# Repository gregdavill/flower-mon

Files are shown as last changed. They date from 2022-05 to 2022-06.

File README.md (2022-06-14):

# Zigbee Plant Watering Sensor

New circuit board layout based off the following projects:
 - https://github.com/smartboxchannel/Plant-Watering-Sensor-Zigbee
 - https://github.com/diyruz/flower

Capacitance sensor soil moisture sensor based on the CC2530 SoC.
Designed to communicate over Zigbee to a coordinator.
Powered from a CR2032, optional humidity, and temperature sensors.

## Photo
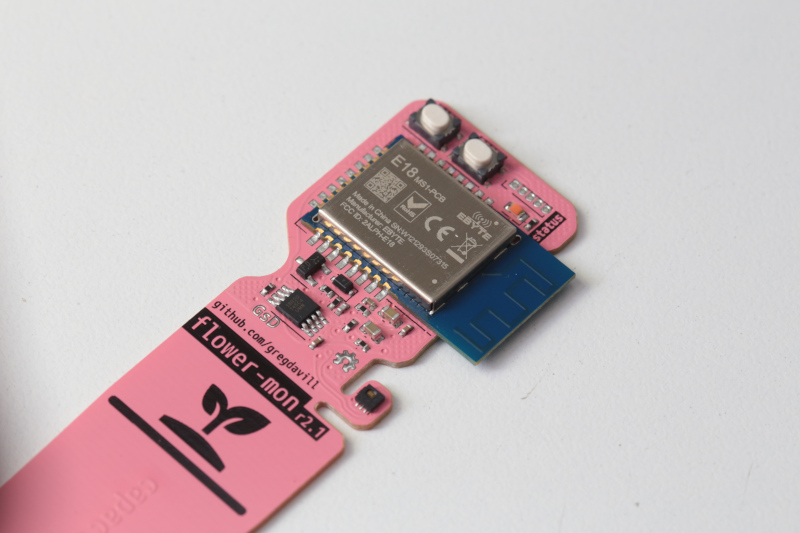
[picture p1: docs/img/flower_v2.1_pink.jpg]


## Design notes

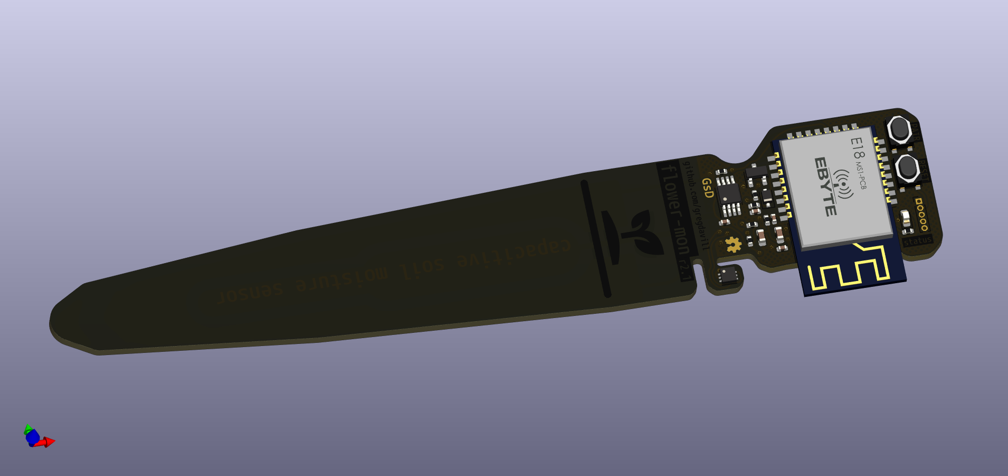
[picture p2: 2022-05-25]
docs/img/flower_v2.1_01.png

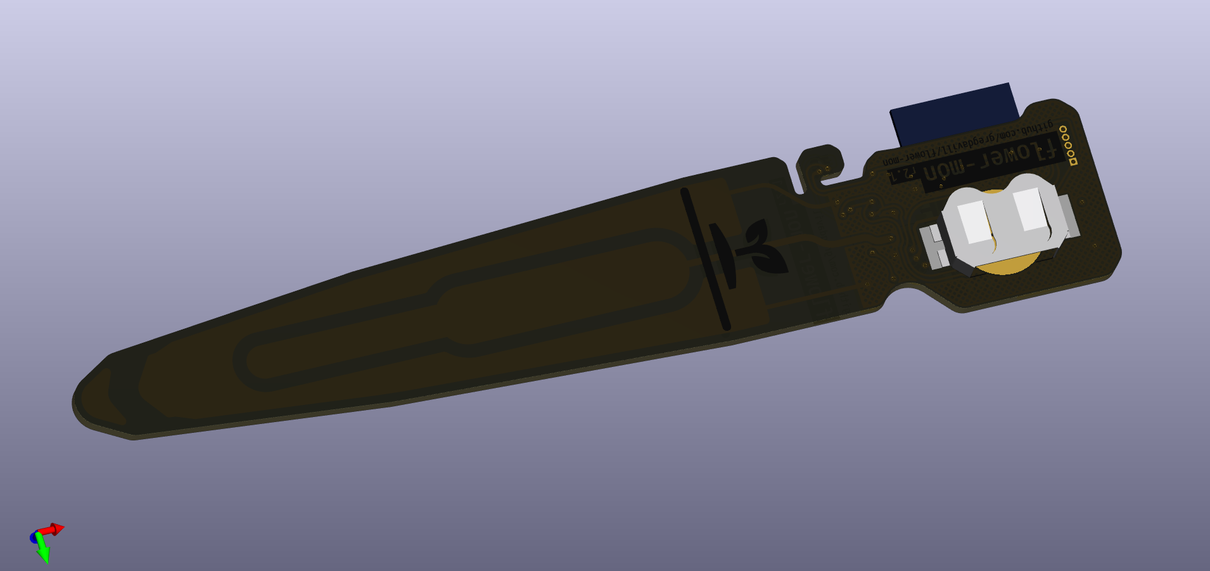
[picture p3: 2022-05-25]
docs/img/flower_v2.1_02.png

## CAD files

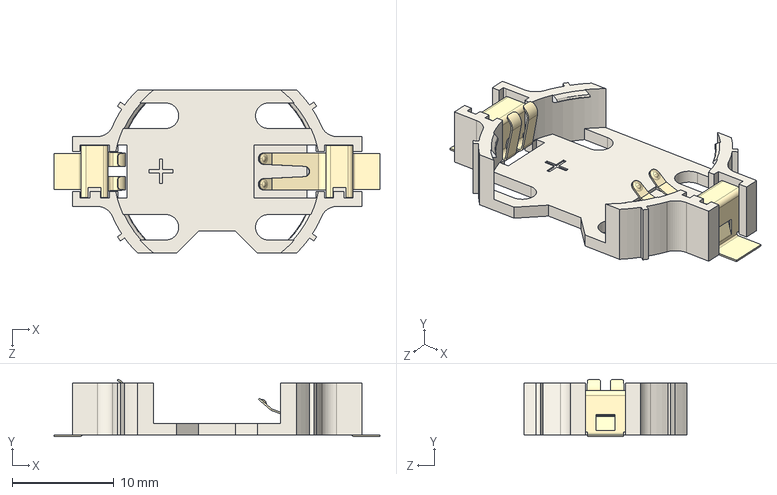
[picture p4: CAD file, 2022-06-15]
kicad-src/3d/keystone-PN1058.STEP
32.0 x 5.63 x 16.0 mm

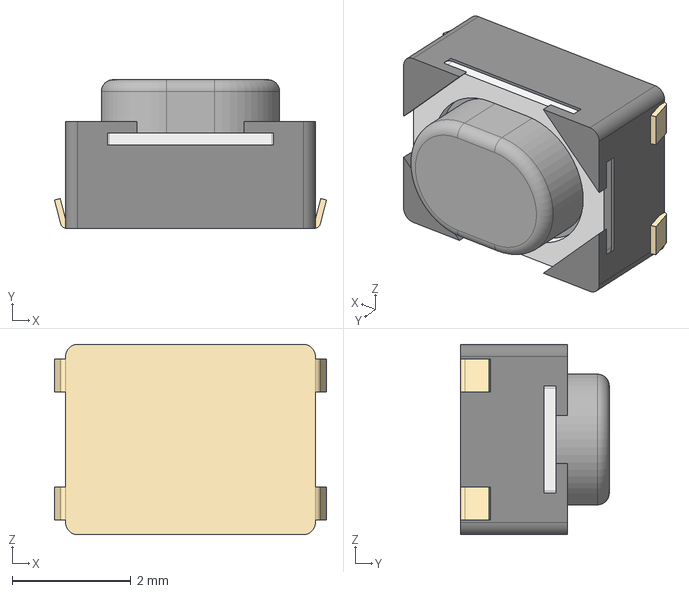
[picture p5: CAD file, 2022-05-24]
kicad-src/3d/PTS810SJG250SMTRLFS.step
4.58 x 2.50 x 3.20 mm

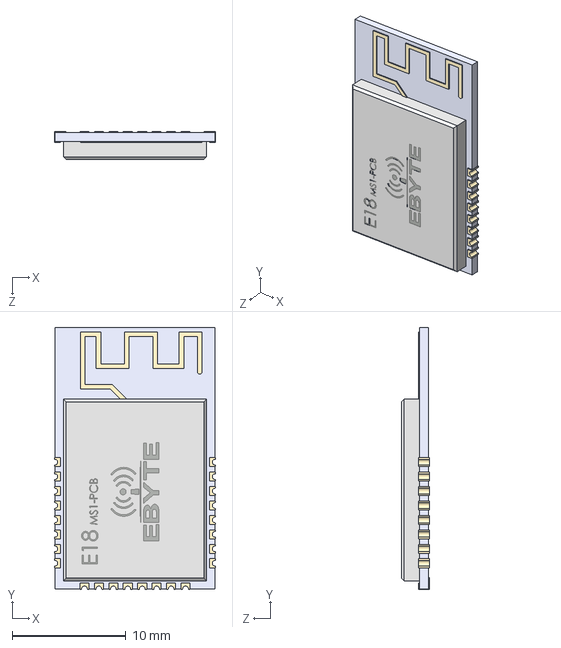
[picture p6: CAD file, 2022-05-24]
kicad-src/3d/e18-ms1-pcb.STEP
14.2 x 23.1 x 2.50 mm
plate
контакт x 24

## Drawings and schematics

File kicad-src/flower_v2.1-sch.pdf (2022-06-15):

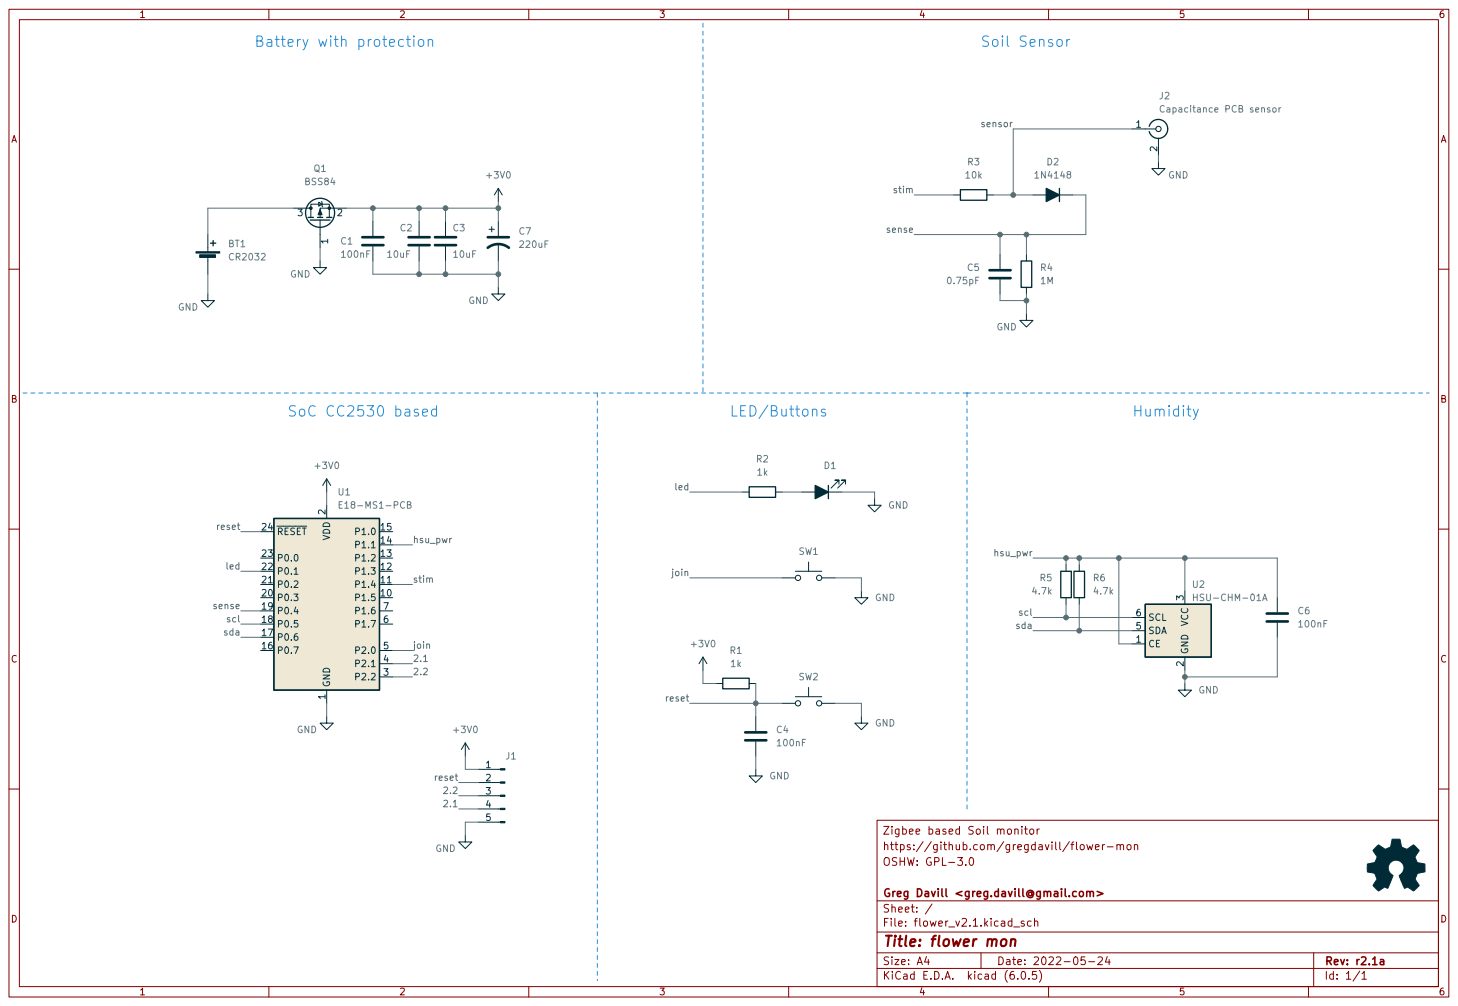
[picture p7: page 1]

3 SDA 5 SCL 6 U2HSU-CHM-01A GND

2 P0.3 20 P0.2 21 P0.1 22 P0.0 23 ~{RESET} 24 P2.2 3 P2.1 4 P2.0 5 P1.7 6 P1.6 7 U1E18-MS1-PCB GND GND

https://github.com/gregdavill/flower-mon
File: flower_v2.1.kicad_sch Sheet: / Greg Davill <greg.davill@gmail.com> OSHW: GPL-3.0

Id: 1/1 Title: flower mon

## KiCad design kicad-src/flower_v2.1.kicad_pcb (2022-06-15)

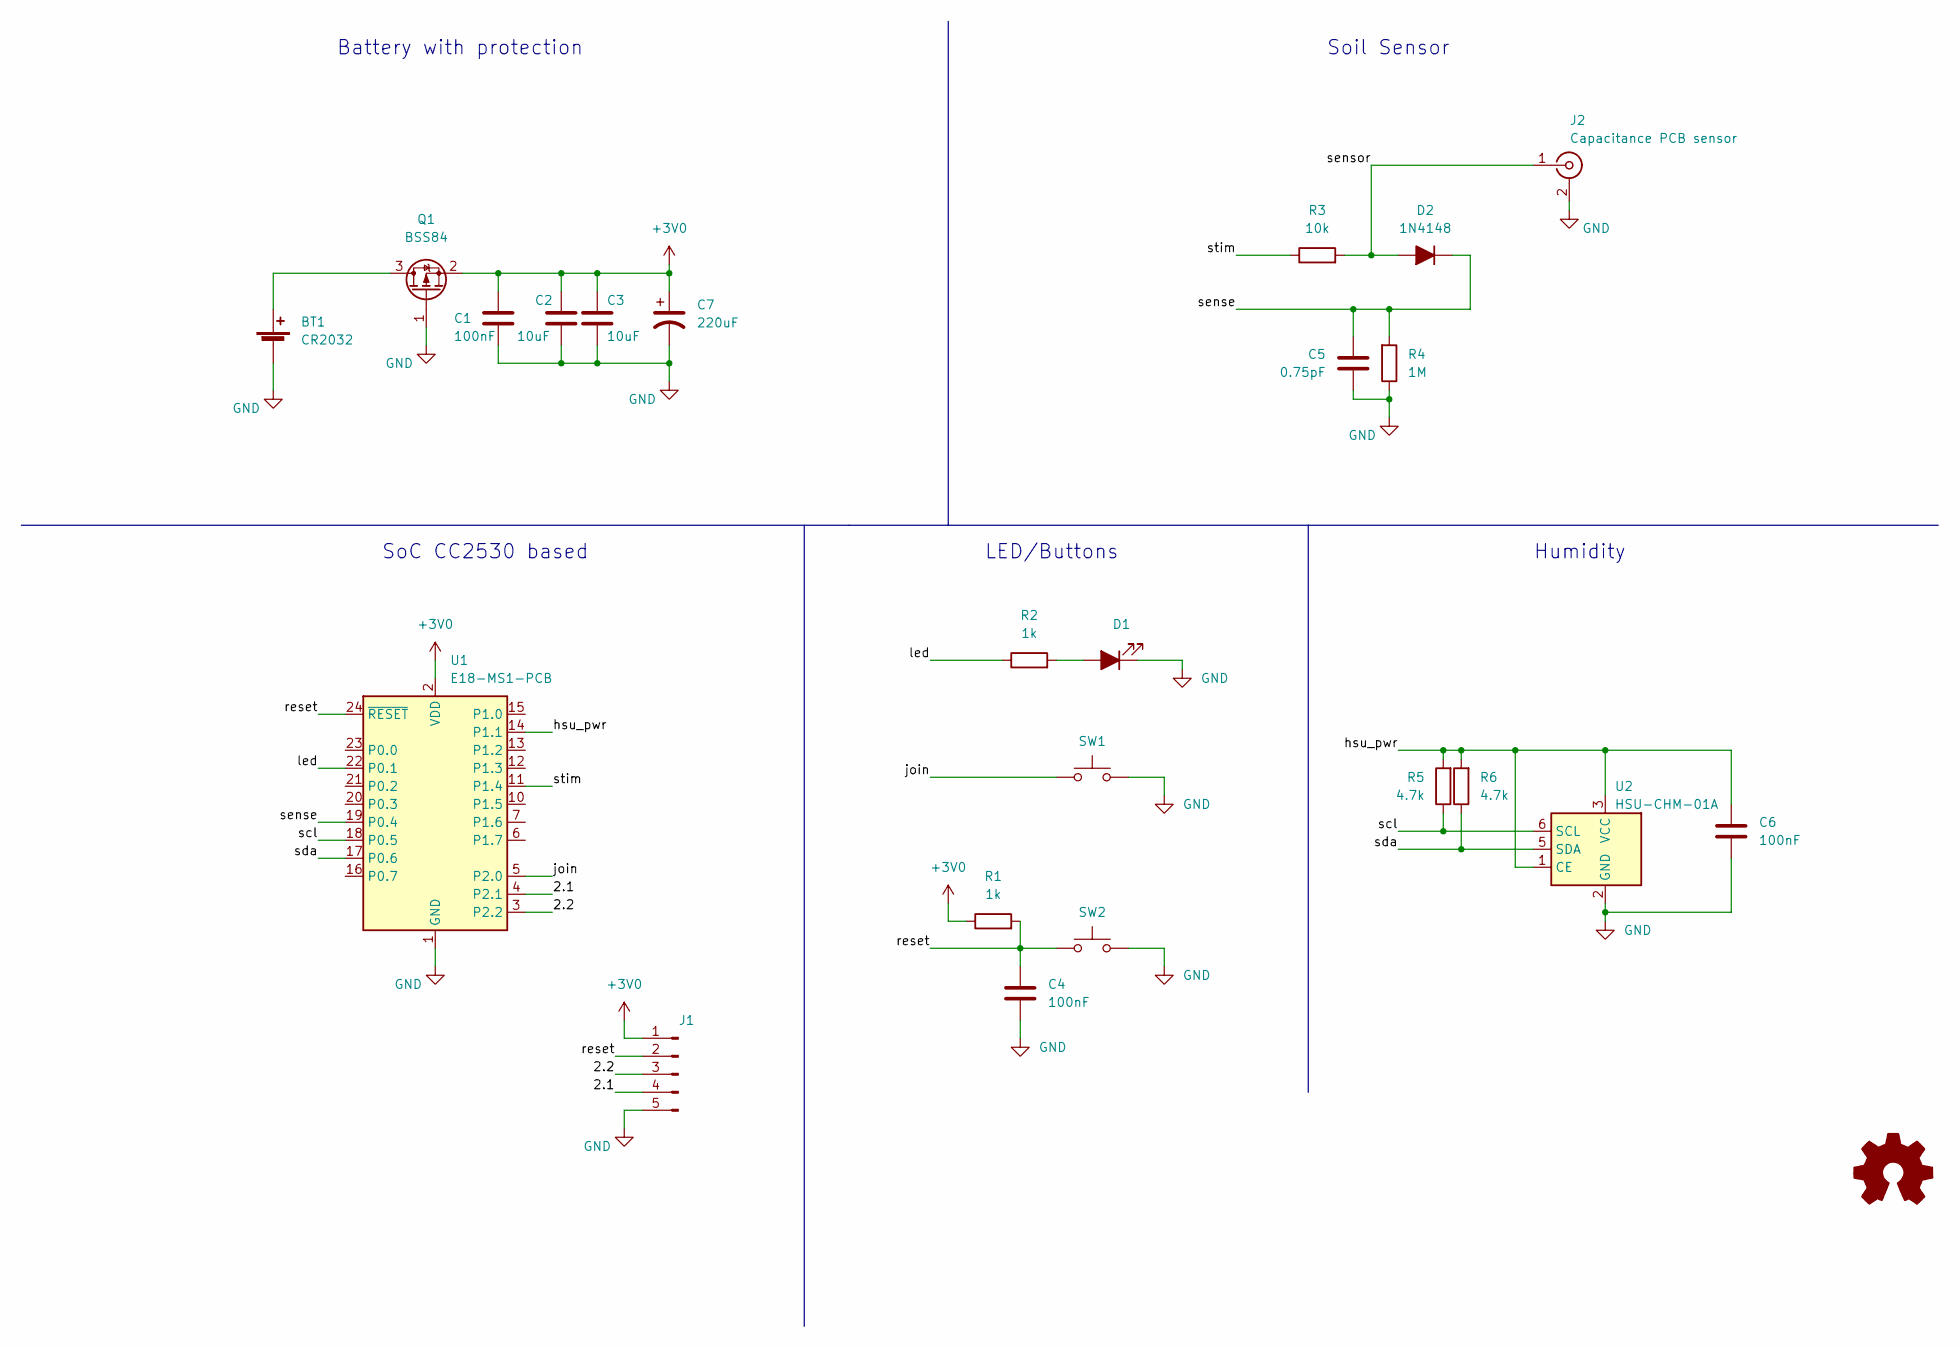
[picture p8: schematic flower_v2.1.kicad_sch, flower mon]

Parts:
BT1: CR2032; keystone_1058
C1, C4, C6: 100nF; C_0402_1005Metric
C2, C3: 10uF; C_0603_1608Metric
C5: 0.75pF; C_0402_1005Metric
C7: 220uF; CP_EIA-3528-21_Kemet-B
D1: green; LED_0603_1608Metric
D2: 1N4148; D_SOD-323F
J1: Conn_01x05_Male; PinHeader_1x05_P1.00mm_Vertical
J2: Capacitance PCB sensor
Q1: BSS84; SOT-23
R1, R2: 1k; R_0402_1005Metric
R3: 10k; R_0402_1005Metric
R4: 1M; R_0402_1005Metric
R5, R6: 4.7k; R_0402_1005Metric
SW1, SW2: SW_Push; SW_SPST_PTS810
U1: E18-MS1-PCB
U2: HSU-CHM-01A; DFN-6-1EP_2x2mm_P0.5mm_EP0.61x1.42mm

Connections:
+3V0: C1.1, C2.1, C3.1, C7.1, J1.1, Q1.2 (S), R1.1, U1.2 (VDD)
/2.1: J1.4, U1.4 (P2.1)
/2.2: J1.3, U1.3 (P2.2)
/hsu_pwr: C6.1, R5.2, R6.2, U1.14 (P1.1), U2.1 (CE), U2.3 (VCC)
/join: SW1.1, U1.5 (P2.0)
/led: R2.1, U1.22 (P0.1)
/reset: C4.1, J1.2, R1.2, SW2.1, U1.24 (~RESET)
/scl: R5.1, U1.18 (P0.5), U2.6 (SCL)
/sda: R6.1, U1.17 (P0.6), U2.5 (SDA)
/sense: C5.1, D2.1 (K), R4.2, U1.19 (P0.4)
/sensor: D2.2 (A), J2.1 (In), R3.2
/stim: R3.1, U1.11 (P1.4)
GND: BT1.2 (-), C1.2, C2.2, C3.2, C4.2, C5.2, C6.2, C7.2, D1.1 (K), J1.5, J2.2 (Ext), Q1.1 (G), R4.1, SW1.2, SW2.2, U1.1 (GND), U2.2 (GND)
unnamed: BT1.1 (+), Q1.3 (D)
unnamed: D1.2 (A), R2.2

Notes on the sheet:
Battery with protection
Humidity
SoC CC2530 based
Soil Sensor
LED/Buttons

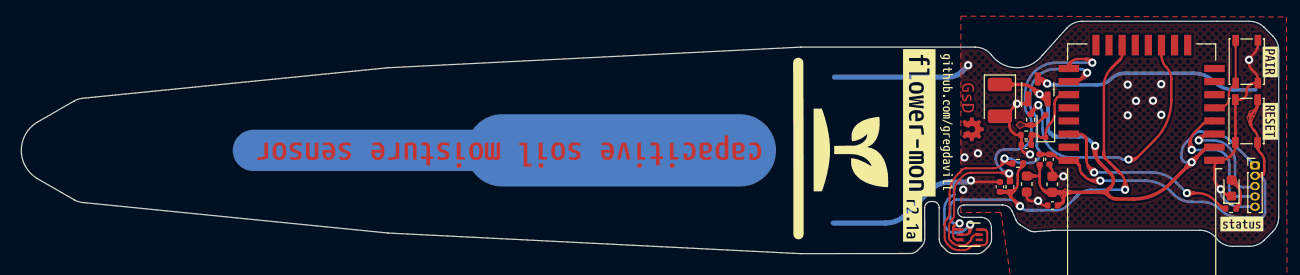
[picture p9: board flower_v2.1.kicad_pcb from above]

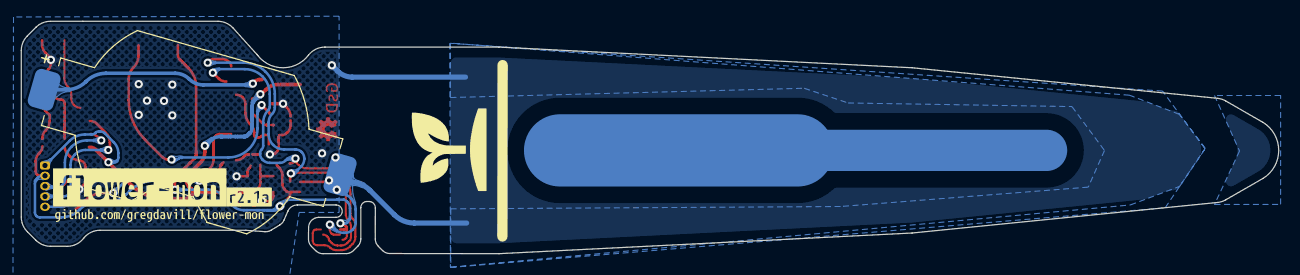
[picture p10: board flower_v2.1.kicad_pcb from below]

Board: 2 copper layers, 121.7 x 22.5 mm, 32 parts (4 on the bottom side), 15 nets.

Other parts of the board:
kibuzzard-62A9BF5E: G***; kibuzzard-62A9BF5E
kibuzzard-62A9BF6E: G***; kibuzzard-62A9BF6E
kibuzzard-628C3F80: G***; kibuzzard-628C3F80
kibuzzard-628C3FD2: G***; kibuzzard-628C3FD2
kibuzzard-628C3FDC: G***; kibuzzard-628C3FDC
kibuzzard-628C36A2: G***; kibuzzard-628C36A2
kibuzzard-628C37D3: G***; kibuzzard-628C37D3
kibuzzard-628CB3EE: G***; kibuzzard-628CB3EE
kibuzzard-628D81B8: G***; kibuzzard-628D81B8
kibuzzard-628D81CB: G***; kibuzzard-628D81CB

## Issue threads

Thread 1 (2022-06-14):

r2.1 hardware: HSU-CHM-01A symbol incorrect

gregdavill, 2022-06-14:
## Summary

The symbol for the sensor has pins 2/3 swapped :(

## Fix

It's possible to fix with a bodge on the PCB

Closed 2022-06-15.

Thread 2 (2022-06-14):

r2.1 hardware: Missing large capacitor in parallel with coin cell

gregdavill, 2022-06-14:
## Summary

There is only ~20uF of capacitance with the coin cell.
In many other sensor designs a 220uF or 470uF tantalum cap is added, this helps to reduce power loss from the coin cells high ESR.

Closed 2022-06-15.

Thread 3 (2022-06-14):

r2.1 hardware: DS18B20 is redundant

gregdavill, 2022-06-14:
## Summary

The humidity sensor is lower power, quick and also features an accurate temperature measurement.

Closed 2022-06-15.

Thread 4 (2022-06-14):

r2.1 hardware: Battery footprint is not for a CR2032

gregdavill, 2022-06-14:
## Summary

Somehow managed to convince myself that the small battery holder I designed in was a CR2032 type, it's clearly too small.

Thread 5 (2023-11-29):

Fabrication and functional status

mrgsts, 2023-11-29:
Hello, have you being able to produce and make it working? i also see that he latest kicad pcb seems to have some connections missing

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

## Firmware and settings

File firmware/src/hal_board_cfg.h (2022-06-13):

#ifndef HAL_BOARD_CFG_H
#define HAL_BOARD_CFG_H


/* ------------------------------------------------------------------------------------------------
 *                                           Includes
 * ------------------------------------------------------------------------------------------------
 */

#include "hal_mcu.h"
#include "hal_defs.h"
#include "hal_types.h"







/* ------------------------------------------------------------------------------------------------
 *                                          Clock Speed
 * ------------------------------------------------------------------------------------------------
 */

#define HAL_CPU_CLOCK_MHZ     32

/* 32 kHz clock source select in CLKCONCMD */
#if !defined (OSC32K_CRYSTAL_INSTALLED) || (defined (OSC32K_CRYSTAL_INSTALLED) && (OSC32K_CRYSTAL_INSTALLED == TRUE))
#define OSC_32KHZ  0x00 /* external 32 KHz xosc */
#else
#define OSC_32KHZ  0x80 /* internal 32 KHz rcosc */
#endif

#define HAL_CLOCK_STABLE() 

/* ------------------------------------------------------------------------------------------------
 *                                         Key Release detect support
 * ------------------------------------------------------------------------------------------------
 */
#define HAL_KEY_CODE_NOKEY 0xff


/* ------------------------------------------------------------------------------------------------
 *                                       LED Configuration
 * ------------------------------------------------------------------------------------------------
 */

// TODO: review all HAL_BOARD_CC2530EB_REV17 and replace with HAL_BOARD_CC2530RC
//       if applicable.
#define HAL_NUM_LEDS            1

#define HAL_LED_BLINK_DELAY()   st( { volatile uint32 i; for (i=0; i<0x5800; i++) { }; } )
#define ACTIVE_LOW        !
#define ACTIVE_HIGH       !!    /* double negation forces result to be '1' */

/* ------------------------------------------------------------------------------------------------
 *                         OSAL NV implemented by internal flash pages.
 * ------------------------------------------------------------------------------------------------
 */

// Flash is partitioned into 8 banks of 32 KB or 16 pages.
#define HAL_FLASH_PAGE_PER_BANK    16
// Flash is constructed of 128 pages of 2 KB.
#define HAL_FLASH_PAGE_SIZE        2048
#define HAL_FLASH_WORD_SIZE        4

// CODE banks get mapped into the XDATA range 8000-FFFF.
#define HAL_FLASH_PAGE_MAP         0x8000

// The last 16 bytes of the last available page are reserved for flash lock bits.
// NV page definitions must coincide with segment declaration in project *.xcl file.
#if defined NON_BANKED
#define HAL_FLASH_LOCK_BITS        16
#define HAL_NV_PAGE_END            30
#define HAL_NV_PAGE_CNT            2
#else
#define HAL_FLASH_LOCK_BITS        16
#define HAL_NV_PAGE_END            126
#define HAL_NV_PAGE_CNT            6
#endif

// Re-defining Z_EXTADDR_LEN here so as not to include a Z-Stack .h file.
#define HAL_FLASH_IEEE_SIZE        8
#define HAL_FLASH_IEEE_PAGE       (HAL_NV_PAGE_END+1)
#define HAL_FLASH_IEEE_OSET       (HAL_FLASH_PAGE_SIZE - HAL_FLASH_LOCK_BITS - HAL_FLASH_IEEE_SIZE)
#define HAL_INFOP_IEEE_OSET        0xC

#define HAL_FLASH_DEV_PRIVATE_KEY_OSET     0x7D2
#define HAL_FLASH_CA_PUBLIC_KEY_OSET       0x7BC
#define HAL_FLASH_IMPLICIT_CERT_OSET       0x78C

#define HAL_NV_PAGE_BEG           (HAL_NV_PAGE_END-HAL_NV_PAGE_CNT+1)
// Used by DMA macros to shift 1 to create a mask for DMA registers.
#define HAL_NV_DMA_CH              0
#define HAL_DMA_CH_RX              3
#define HAL_DMA_CH_TX              4

#define HAL_NV_DMA_GET_DESC()      HAL_DMA_GET_DESC0()
#define HAL_NV_DMA_SET_ADDR(a)     HAL_DMA_SET_ADDR_DESC0((a))

/* ------------------------------------------------------------------------------------------------
 *  Serial Boot Loader: reserving the first 4 pages of flash and other memory in cc2530-sb.xcl.
 * ------------------------------------------------------------------------------------------------
 */

#define HAL_SB_IMG_ADDR       0x2000
#define HAL_SB_CRC_ADDR       0x2090
// Size of internal flash less 4 pages for boot loader, 6 pages for NV, & 1 page for lock bits.
#define HAL_SB_IMG_SIZE      (0x40000 - 0x2000 - 0x3000 - 0x0800)

/* ------------------------------------------------------------------------------------------------
 *                                            Macros
 * ------------------------------------------------------------------------------------------------
 */

/* ----------- RF-frontend Connection Initialization ---------- */
#if defined HAL_PA_LNA || defined HAL_PA_LNA_CC2590
extern void MAC_RfFrontendSetup(void);
#define HAL_BOARD_RF_FRONTEND_SETUP() MAC_RfFrontendSetup()
#else
#define HAL_BOARD_RF_FRONTEND_SETUP()
#endif
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

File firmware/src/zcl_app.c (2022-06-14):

#include "zcl_app.h"

#include <stdio.h>
#include <stdlib.h>

#include "AF.h"
#include "Debug.h"
#include "OSAL.h"
#include "OSAL_Clock.h"
#include "OSAL_PwrMgr.h"
#include "OnBoard.h"
#include "ZComDef.h"
#include "ZDApp.h"
#include "ZDNwkMgr.h"
#include "ZDObject.h"
#include "bdb.h"
#include "bdb_interface.h"
#include "gp_interface.h"
#include "math.h"
#include "nwk_util.h"
#include "zcl.h"
#include "zcl_diagnostic.h"
#include "zcl_general.h"
#include "zcl_ms.h"

/* HAL */
#include "battery.h"
#include "commissioning.h"
#include "factory_reset.h"
#include "hal_adc.h"
#include "hal_drivers.h"
#include "hal_i2c.h"
#include "hal_key.h"
#include "hal_led.h"
#include "inttempsens.h"
#include "utils.h"
#include "version.h"

/*********************************************************************
 * MACROS
 */
#define HAL_KEY_CODE_RELEASE_KEY HAL_KEY_CODE_NOKEY

/*********************************************************************
 * CONSTANTS
 */

/*********************************************************************
 * TYPEDEFS
 */

/*********************************************************************
 * GLOBAL VARIABLES
 */

byte zclApp_TaskID;

/*********************************************************************
 * GLOBAL FUNCTIONS
 */

/*********************************************************************
 * LOCAL VARIABLES
 */

static uint8 currentSensorsReadingPhase = 0;
int16 temp_old = 0;
int16 tempTr = 1;
int16 startWork = 0;
bool pushBut = false;

/*********************************************************************
 * LOCAL FUNCTIONS
 */
static void zclApp_HandleKeys(byte shift, byte keys);
static void zclApp_Report(void);

static void zclApp_ReadSensors(void);
#ifndef PWS_MINI
static void zclApp_IntTempSens(void);
#endif
static void zclApp_ReadSoilHumidity(void);
static bool zclApp_StartReadHumiditiyMeasurment(void);
static void zclApp_ReadHumiditiy(void);
static void zclApp_InitPWM(void);
void zclApp_BatteryReport(void); 

static void zcl_BasicResetCB(void);

static void zclApp_EnableSensorPWR(void){
    LREP("Powering Up Sensors\r\n");
    P1DIR |= BV(1);
    P1 |= BV(1);

    // tri state P0.4 (soil humidity pin)
    P0DIR &= ~BV(4);
    P0INP |= BV(4);
}

static void zclApp_DisableSensorPWR(void){
    LREP("Powering Down Sensors \r\n");
    P1SEL  &= ~BV(7);                    // Disable Rx on P1.
    P1DIR |= BV(0) | BV(1) | BV(2) | BV(3) | BV(5) | BV(6) | BV(7);
    P1 &= ~(BV(0) | BV(1) | BV(2) | BV(3) | BV(5) | BV(6) | BV(7));
    P1INP &= ~(BV(0) | BV(1) | BV(2) | BV(3) | BV(5) | BV(6) | BV(7));
    
    P0DIR |= BV(0) | BV(1) | BV(2) | BV(3) | BV(4) | BV(7);
    
    P0 &= ~(BV(0) | BV(1) | BV(2) | BV(3) | BV(4) | BV(7));
    P0INP |= (BV(0) | BV(1) | BV(2) | BV(3) | BV(4) | BV(7));

    P2DIR |= BV(1) | BV(2);
    P2 &= ~(BV(1) | BV(2));

    APCFG = 0;                          // Disable ADC on all I/O
}



/*********************************************************************
 * ZCL General Profile Callback table
 */
static zclGeneral_AppCallbacks_t zclApp_CmdCallbacks = {
    zcl_BasicResetCB,  // Basic Cluster Reset command
    NULL,              // Identify Trigger Effect command
    NULL,              // On/Off cluster commands
    NULL,              // On/Off cluster enhanced command Off with Effect
    NULL,              // On/Off cluster enhanced command On with Recall Global Scene
    NULL,              // On/Off cluster enhanced command On with Timed Off
    NULL,              // RSSI Location command
    NULL               // RSSI Location Response command
};

void zclApp_Init(byte task_id) {
    LREP("Started build %s \r\n", zclApp_DateCodeNT);

    zclApp_EnableSensorPWR();


    zclApp_DisableSensorPWR();


    zclApp_InitPWM();
    HalI2CInit();

    zclApp_TaskID = task_id;
    bdb_RegisterSimpleDescriptor(&zclApp_Desc);

    zclGeneral_RegisterCmdCallbacks(zclApp_Desc.EndPoint, &zclApp_CmdCallbacks);

    /* Run an inital sensor measurement */
    zclSampleTemperatureSensor_ResetAttributesToDefaultValues();
    osal_start_timerEx(zclApp_TaskID, APP_READ_SENSORS_EVT, 5000);
    //user_delay_ms(10);
    
    zcl_registerAttrList(zclApp_Desc.EndPoint, zclApp_NumAttributes, zclApp_AttrsFirstEP);
    zcl_registerForMsg(zclApp_TaskID);

    // Register for all key events - This app will handle all key events
    RegisterForKeys(zclApp_TaskID);


    /* 5m interval */
    osal_start_reload_timer(zclApp_TaskID, APP_REPORT_EVT, ((uint32) (1000UL * 60 * 5)));
}

uint16 zclApp_event_loop(uint8 task_id, uint16 events) {
    afIncomingMSGPacket_t *MSGpkt;

    (void)task_id;  // Intentionally unreferenced parameter
    if (events & SYS_EVENT_MSG) {
        while ((MSGpkt = (afIncomingMSGPacket_t *)osal_msg_receive(zclApp_TaskID))) {
            switch (MSGpkt->hdr.event) {
                case KEY_CHANGE:
                    zclApp_HandleKeys(((keyChange_t *)MSGpkt)->state, ((keyChange_t *)MSGpkt)->keys);
                    break;
                case ZCL_INCOMING_MSG:
                    if (((zclIncomingMsg_t *)MSGpkt)->attrCmd) {
                        osal_mem_free(((zclIncomingMsg_t *)MSGpkt)->attrCmd);
                    }
                    break;

                default:
                    break;
            }
            // Release the memory
            osal_msg_deallocate((uint8 *)MSGpkt);
        }
        // return unprocessed events
        return (events ^ SYS_EVENT_MSG);
    }

    if (events & APP_REPORT_EVT) {
        LREPMaster("APP_REPORT_EVT\r\n");
        zclApp_Report();
        return (events ^ APP_REPORT_EVT);
    }

    if (events & APP_READ_SENSORS_EVT) {
        LREPMaster("APP_READ_SENSORS_EVT\r\n");
        zclApp_ReadSensors();
        return (events ^ APP_READ_SENSORS_EVT);
    }

    // Discard unknown events
    return 0;
}

static void zclApp_HandleKeys(byte portAndAction, byte keyCode) {
    LREP("zclApp_HandleKeys portAndAction=0x%X keyCode=0x%X\r\n", portAndAction, keyCode);
    zclFactoryResetter_HandleKeys(portAndAction, keyCode);
    zclCommissioning_HandleKeys(portAndAction, keyCode);
    if (portAndAction & HAL_KEY_RELEASE) {
        LREPMaster("Key Release\r\n");  
        if (bdbAttributes.bdbNodeIsOnANetwork) {
            osal_start_timerEx(zclApp_TaskID, APP_READ_SENSORS_EVT, 5000);
        } else {
            osal_start_timerEx(zclApp_TaskID, APP_READ_SENSORS_EVT, 5000);
        }
        HalLedSet(HAL_LED_1, HAL_LED_MODE_BLINK);
        pushBut = true;
    }
}
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

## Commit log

2022-05-25 Update PCB layout
    [flower_v2.1.kicad_pcb, flower_v2.1.kicad_sch]
2022-06-11 Update firmware
    - Fix compile issues by fixing include case
    [zcl_app.c, zcl_app.h]
2022-06-13 Update zstack-lib
    - Fix inital battery values on POR
    - Add support for UART debugging with power saving enabled
2022-06-13 Apply fixes to Z-Stack
    - Add event for UART_TX_IDLE
2022-06-13 Z-Stack: PM2 + UART DMA bug fix
2022-06-13 Reduce power consumption
    - The OW data pin was left with a pullup, causing ~100uA of leakage.
    [zcl_app.c]
2022-06-13 Upidate firmware
    - Rework i2c library to improve speed, and reduce duplicated code
    - Add Humidity readout
    - Rework sensor sample state machine
    - Fix pull-up Enable/Disable polarity
    - Bump report timer to 5m
    - Add support for HSU-CHM-01A Humidity sensor
    [zcl_app.c, zcl_app.h]
2022-06-14 Firmware fix PWM output to soil sensor
    [zcl_app.c]
2022-06-14 fw: fix local/global variable bug
    [zcl_app.c]
2022-06-15 hw2.1a: Fix HSU-CHM footprint
    Fixes #1
    [flower_v2.1.kicad_pcb, flower_v2.1.kicad_sch]
2022-06-15 hw2.1a: Fix bugs
    - Added 220uF Tantulum cap, fixes #2
    - Removed DS18B20, fixes #3
    - Updated battery footprint, fixes #4
    [flower_v2.1.kicad_pcb, flower_v2.1.kicad_sch, keystone-PN1058.STEP]
